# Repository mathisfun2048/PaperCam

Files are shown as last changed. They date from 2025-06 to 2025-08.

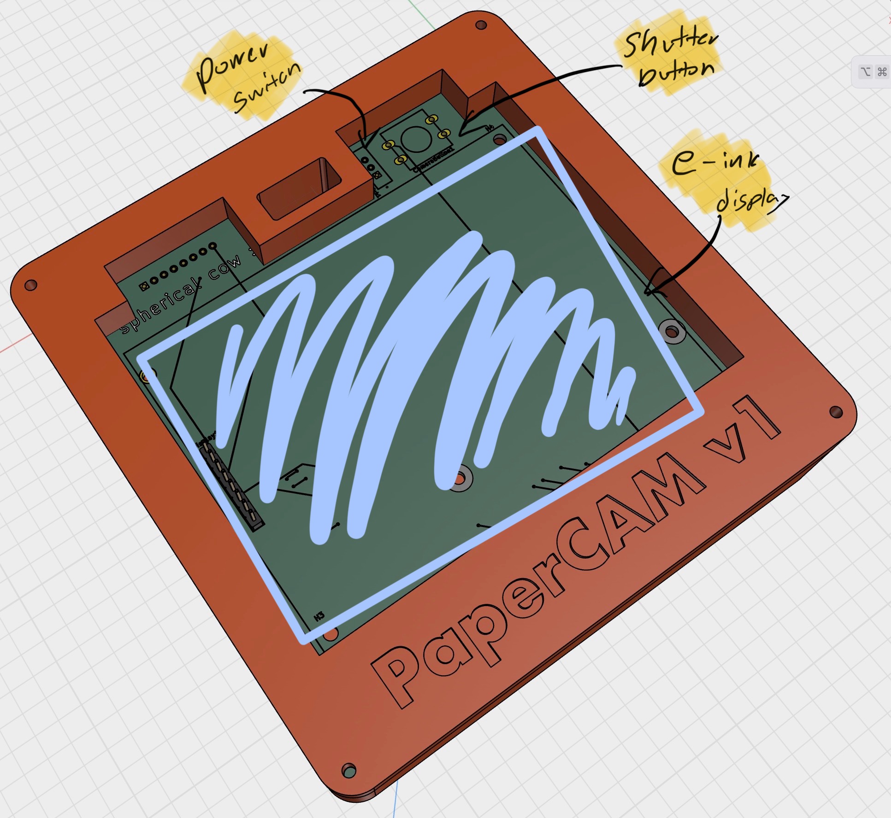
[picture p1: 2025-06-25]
assets/IMG_4889.jpeg

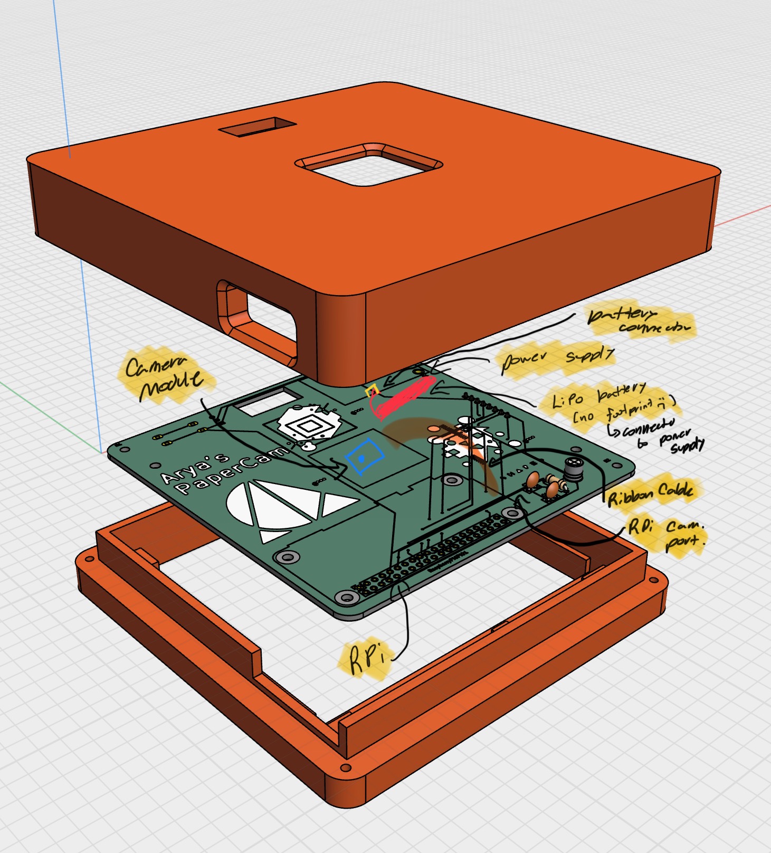
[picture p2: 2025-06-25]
assets/IMG_4890.jpg

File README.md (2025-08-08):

# PaperCam: My Thought Process Behind This Project



## Description and Exigence

This is my third attempt at hardware design, and it's been so much fun!

The concept arose when I came across ads for disposable cameras for summer camps on YouTube. I remembered the nostalgia of taking instant pictures and the intrinsic joy they bring, but within the context of instant cameras being 1) expensive and 2) harmful to the environment. I want to bridge this gap by creating a digital camera that feels like an instant camera. 

The first thing I think of with instant photography is not knowing exactly how the picture is going to turn out; rather, just taking it and hoping for the best. That's why instead of opting for an LCD display, I chose an E-Ink display. Not only does it use significantly less power, but it can also show an instant snapshot *after* taking the picture, mimicking the feeling of instant photography. 

Another goal I had for this project was to intentionally keep things minimalistic. In a world where technology can have so many features, I wanted to create something simple with one purpose: taking a picture. There's this one Japanese brand (Muji!) that I have been enthralled with for the past 7 years, mainly due to their product's simplicity. Keeping this in mind, I was very mindful of which parts I needed to use. The only user inputs, really, are a power switch and a capture button, nothing excessive but enough to take a picture. Moreover, the e-ink display shows a glimpse of the photo after it has been taken, not necessarily the most detailed, but accurate enough to capture the likeness of whatever is being captured. I hope that this camera will encourage me to try to create memories instead of the best "picture" I hope this camera will let me be less preoccupied with how things look but rather will force me to capture things authentically. 

Here is everything I sourced. A identical version can be found in the BOM tab at the bottom of the README. 

NOTE: I know some items can be found cheaper through other retailars: the only problem is that my parents will only let me buy from the retailors below. If the cost goes above the allocated cost for my project, I will hapilly pay out of my own pocket. I am grateful to have the opportunity to build this, and I cannot do so if I don't buy the parts from the retailors below. 

| item | quantity | cost | source | link |
| --- | --- | --- | --- | --- |
| Raspberry Pi Zero 2 W | 1 | 14.99  | microcenter | [https://www.microcenter.com/product/643085/raspberry-pi-zero-2-w](https://www.microcenter.com/product/643085/raspberry-pi-zero-2-w) |
| Camera | 1 | 29.25  | adafruit | [https://www.adafruit.com/product/5657](https://www.adafruit.com/product/5657) |
| e-ink display | 1 | 34.99  | amazon | [https://www.amazon.com/dp/B074NR1SW2](https://www.amazon.com/dp/B074NR1SW2) |
| 64gb SD Card | 1 | 0 | myself | n/a |
| LiPo Batter 2200mAh | 1 | 9.95 | adafruit | [https://www.adafruit.com/product/1781](https://www.adafruit.com/product/1781) |
| powerboost 1000c | 1 | 19.95  | adafruit | [https://www.adafruit.com/product/2465?srsltid=AfmBOop7pYqBCCEfueczVoFC1WawLn-4JDxrWe6MvBLNL__PzA9LbI22](https://www.adafruit.com/product/2465?srsltid=AfmBOop7pYqBCCEfueczVoFC1WawLn-4JDxrWe6MvBLNL__PzA9LbI22) |
| SPDT Switch | 1 | 0.95 | adafruit | [https://www.adafruit.com/product/805](https://www.adafruit.com/product/805) |
| 12mm Button | 1 | 5.95 | adafruit | [https://www.adafruit.com/product/1010](https://www.adafruit.com/product/1010) |
| Header for RPi | 1 | 1.75 | adafruit | [https://www.adafruit.com/product/3907](https://www.adafruit.com/product/3907) |
| 0.1uF Ceramic Capacitor | 2 | 1.95 | adafruit | [https://www.adafruit.com/product/753](https://www.adafruit.com/product/753) |
| 220uF Electrolytic Capacitor | 1 | 2.95 | adafruit | [https://www.adafruit.com/product/2192](https://www.adafruit.com/product/2192) |
| Screws M2.5 × 6 mm \* 5, M2.5 x 10 mm \* 4 | 9 | 16.95  | adafruit | [https://www.adafruit.com/product/3299](https://www.adafruit.com/product/3299) |
| Custom PCB | 1 | 8.6 | JCLPCB | [https://jlcpcb.com](https://jlcpcb.com/) |
| Total Cost | | ~148 |

## Schematic and PCB Design

I saw that with this project, spending all this time curating the BOM allowed my schematic and PCB design process to be significantly smoother. I was able to organically decide where components go such that the product can fulfill its purpose without having anything excess. I feel this starked my approach in my Hackpad design, where I flooded the PCB with an LED matrix, OLED, and encoder when perhaps the keys would have sufficed. The design of this project has been meditative, and I am grateful for that. One way I referenced this creative meditation in the design itself is through the inclusion of graphic design motifs I designed during the pandemic. The graphic design kept me sane then through its meditative nature, and I wanted to reference that simple creativity in the silkscreen. I will say that the silkscreen aesthetic starks the clean minimalistic nature of the CAD, and that is intentional: my graphic design motifs, in all their chaos, are a part of me and do not necessarily need to be advertised. To the user, I want the product to be simple elegant, and perfect for capturing memories. 

### Schematic

Screenshot 2025-07-02 at 4 30 53 AM

### PCB on Kicad

Screenshot 2025-07-02 at 4 30 31 AM

## Firmware

After I designed the PCB, I started on the firmware, the design of which garnered me the most personal growth. While I was able to exercise my research and design skills to a significantly larger extent in this project compared to Hackpad or Gamepad, the software designed for this is something I have never done before. I have never had multiple software files interact with each other in a product before. For instance, I started this project initially with just a runtime firmware, but then realized I needed to use shell too to initiate my code and the file structure and use the system to restart my Python code should it crash. I spent quite a bit coding, but I saw myself getting faster at it which amazed me. I started learning how to code maybe 2 years ago, and I am really proud of what I've been able to do here. 

Everything associated with the firmware can be found in the firmware directory. It has its own specialized README that explains what each file does. 

## CAD

After I was done with the code, I saved the hardest for last: CAD. I've never been good at CAD, but this project allowed me to show my style. When I did graphic design, I specialized in minimalistic designs which were meant to be abstract and aesthetically pleasing. I was highly influenced by the Bauhaus movement, and I am so glad I was able to incorporate that part of my personal style into this project. In keeping line with the "minimal" mindset, I wanted the design to be a simplified square Instax. That's why on the exterior form it almost looks like a kid's toy-- that is intentional. I don't want anything to distract from my camera being used to capture memories, even if it looks a tad blocky (I personally think it looks pretty cool). Making it look seamless on the outside was not easy, though. I utilized a top-case, bottom-case design where my PCB will screw into the bottom case before the top case is applied and the whole thing is screwed together. This required me to be able to hide my mounting screws inside the structure--the inside is much more chaotic than the clean exterior. For stability, I chose to indent the inside a tad so that the top case slides on and has a sense of rigidity. This is enhanced by the view-finder which acts as a "pole" holding everything together. I wanted my camera to not feel like something inherently precious, but rather something that can be taken places and used as a camera to capture memories. The only real adoration I have for it is the phrase "PaperCAM v1" on the user side of it. I want to remind myself that when I use this, it is something that I built and not something I simply bought. I want to remind myself that I have the agency to create things. 

Because everything is on a PCB this time, no fun illustrated wiring diagram :(. However, I did annotate the bellow images for y'all! 






## BOM

NOTE: I know some items can be found cheaper through other retailars: the only problem is that my parents will only let me buy from the retailors below. If the cost goes above teh allocated cost for my project, I will hapilly pay out of my own pocket. I am grateful to have the opportunity to build this, and I cannot do so if I don't buy the parts from the retailors below. 

| item | quantity | cost | source | link |
| --- | --- | --- | --- | --- |
| Raspberry Pi Zero 2 W | 1 | 14.99  | microcenter | [https://www.microcenter.com/product/643085/raspberry-pi-zero-2-w](https://www.microcenter.com/product/643085/raspberry-pi-zero-2-w) |
| Camera | 1 | 29.25  | adafruit | [https://www.adafruit.com/product/5657](https://www.adafruit.com/product/5657) |
| e-ink display | 1 | 34.99  | amazon | [https://www.amazon.com/dp/B074NR1SW2](https://www.amazon.com/dp/B074NR1SW2) |
| 64gb SD Card | 1 | 0 | myself | n/a |
| LiPo Batter 2200mAh | 1 | 9.95 | adafruit | [https://www.adafruit.com/product/1781](https://www.adafruit.com/product/1781) |
| powerboost 1000c | 1 | 19.95  | adafruit | [https://www.adafruit.com/product/2465?srsltid=AfmBOop7pYqBCCEfueczVoFC1WawLn-4JDxrWe6MvBLNL__PzA9LbI22](https://www.adafruit.com/product/2465?srsltid=AfmBOop7pYqBCCEfueczVoFC1WawLn-4JDxrWe6MvBLNL__PzA9LbI22) |
| SPDT Switch | 1 | 0.95 | adafruit | [https://www.adafruit.com/product/805](https://www.adafruit.com/product/805) |
| 12mm Button | 1 | 5.95 | adafruit | [https://www.adafruit.com/product/1010](https://www.adafruit.com/product/1010) |
| Header for RPi | 1 | 1.75 | adafruit | [https://www.adafruit.com/product/3907](https://www.adafruit.com/product/3907) |
| 0.1uF Ceramic Capacitor | 2 | 1.95 | adafruit | [https://www.adafruit.com/product/753](https://www.adafruit.com/product/753) |
| 220uF Electrolytic Capacitor | 1 | 2.95 | adafruit | [https://www.adafruit.com/product/2192](https://www.adafruit.com/product/2192) |
| Screws M2.5 × 6 mm \* 5, M2.5 x 10 mm \* 4 | 9 | 16.95  | adafruit | [https://www.adafruit.com/product/3299](https://www.adafruit.com/product/3299) |
| Custom PCB | 1 | 8.6 | JCLPCB | [https://jlcpcb.com](https://jlcpcb.com/) |
| Total Cost | | ~148 |

## Parting Words

If you've made it so far, thank you. This project has been really personal for me, I don't know why. In the process, I've discovered more of what I value in design and feel that I have been able to refine my personal style. Because of this project, I think I finally feel confident with CAD. In the coding portions, I learned that I can be an actual DEV and not someone who just does practice problems for some test.

Hackclub and Highway, thank you so much for the opportunity to design and hopefully implement this project. 

Until next time,
Arya

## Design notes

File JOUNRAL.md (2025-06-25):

title: PaperCam

author: Arya C.

description: this project is to create a digital camera that emulates the feeling of a instant camera through the use of an e-ink display.

created: 06/22/2025

total hours so far: 21 hours

# June 22

## 12PM -> 1PM (1 hour)
So I'm in the middle of my LightBox project (which you should totally check out too!) and I got this idea of making a digital camera feel more like a instant camera! Right now I'm not really researching parts or anything (focusing more on LightBox) but I wanted to start this and add my sketch so I remember my train of thought!



# June 23

## 3:30PM -> 5:30PM, 6PM -> 10PM (6 hours)

Spent some time researching various compoennts! A goal I have for this project is to absolulty minimize costs, something I had not looked at before. This was really, stupidly, hard because camera modules are so abundant... but I wanted to make one myself! I'm glad I was able to. Because of this, the PCB will be very minimalistic, but honestly, it might look better that way; it will fit the monocrome e-ink "instant" display. Here are the fruits from my labor in one cool table!

Shoutout to graphic for GPIO pins becasue this because it helped me so much!



| Section | Item | Part Number / Spec | Qty | Buy Link |
| --- | --- | --- | --- | --- |
| **Core** | | | | |
| | Raspberry Pi Zero 2 W | SC1176 | 1 | [microcenter](https://www.microcenter.com/product/643085/raspberry-pi-zero-2-w) |
| | Camera | — | 1 | [adafruit](https://www.adafruit.com/product/5657) |
| | 4.2″ E-Paper 400 × 300 SPI | Waveshare | 1 | [amazon](https://www.amazon.com/dp/B074NR1SW2) |
| | microSD Card 64 GB | SanDisk | 1 | [amazon](https://www.amazon.com/SanDisk-Extreme-microSDXC-Memory-Adapter/dp/B09X7C7LL1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) |
| **Power** | | | | |
| | 18650 Li-ion 2600 mAh | W2655B | 1 | [microcenter](https://www.microcenter.com/product/659302/performance-tools-18650-li-ion-recharge-battery) |
| | PowerBoost 1000 C | Adafruit 1944 | 1 | [adafruit](https://www.adafruit.com/product/2465?srsltid=AfmBOop7pYqBCCEfueczVoFC1WawLn-4JDxrWe6MvBLNL__PzA9LbI22) |
| | Main Power Switch SPDT (TH) | 805 | 1 | [adafruit](https://www.adafruit.com/product/805) |
| **User I/O** | | | | |
| |  12mm Square Tactile Button Switch | 1010 | 1 | [adafruit](https://www.adafruit.com/product/1010) |
| **Headers** | | | | |
| | Raspberry Pi Header | 3907 | 1 | [adafruit](https://www.adafruit.com/product/3907) |
| **Passives** | | | | |
| | 10 kΩ Resistor | 2784 | 1 | [adafruit](https://www.adafruit.com/product/2784) |
| | Decoupling 0.1 µF Ceramic Capacitor | 753 | 2 | [adafruit](https://www.adafruit.com/product/753) |
| | Bulk Cap 220uF 16V Electrolytic Capacitors  | 2192 | 1 | [adafruit](https://www.adafruit.com/product/2192) |
| **Mechanical / PCB** | | | | |
| |  Screws M2.5 × 6 mm * 5, M2.5 x 10 mm * 4 | 3299 | 8 | [adafruit](https://www.adafruit.com/product/3299) |
| | Custom PCB (2-layer 110 × 110 mm ENIG) | n/a | 1 | (JLCPCB / PCBWay whichever is cheaper) |

# June 24

## 10PM -> 3:30AM (5.5 hours)

Okay so I dont know what I was thinking! So when I first made my BOM, I relied on a lot of Digikey because they have everything... and then I saw their shipping! So to optimize, I re-did my BOM with primarily adafruit to keep shipping costs down (the parts I buy from microcenter will be in-person so no shipping). I don't know why but getting in the zen of making the schematic, I was able to think more clearly about the parts and how to use the PCB as an effective canvas for connecting. I don't know why but with my past interactions with PCBs I tried to make it as flashy and complicated as possible, but with my goal of minimalism with this project, I think I appreciate it as being an effective way to wire everything togehter. I am looking forward to see how it all turns out. In the meantime, here is a picture of my schematic!
Screenshot 2025-06-24 at 3 07 51 AM
Screenshot 2025-06-25 at 6 33 33 AM

## 3:30AM -> 4:30AM (1 hour)

Learning experience: plan footprints! So I found out that Kicad does not nativly support my footprints as the symbols are, so I needed to spend a hot minute going through the datasheets for each of my components to select the appropriate footprints. This is what I ended up with: 

Screenshot 2025-06-24 at 4 41 56 AM

Very excited to start building the PCB now!

## 3PM -> 4PM (1 hour)

Started desinging the PCB!

Screenshot 2025-06-24 at 3 19 32 PM

could not finish this in 1 session; I had work. 

# June 25

## 12AM -> 3AM (3 hours)

Finished with the PCB design! Very excited to see this in person :)

### PCB on Kicad
Screenshot 2025-06-25 at 3 04 05 AM
Screenshot 2025-06-25 at 6 34 42 AM
Screenshot 2025-06-25 at 12 37 25 PM

### Front Virtualization
Screenshot 2025-06-25 at 3 04 50 AM
Screenshot 2025-06-25 at 6 36 08 AM
Screenshot 2025-06-25 at 12 37 53 PM

### Back Virtualiation
Screenshot 2025-06-25 at 3 05 29 AM
Screenshot 2025-06-25 at 6 37 18 AM
Screenshot 2025-06-25 at 12 38 31 PM

Now onto software!

## 3AM -> 8AM (5 hours)

quick updated: I connected the LBO to pin 37 so I can get a low-battery notification!

okay so I finished the software!!!!!! 

This was significantly more complicated than coding my hackpad.... that took some intense coding.... yikes

I dont know what screenshots to attach here because, well, everything is just text. 

If you want to see a full software reveal, hit the software directory in this repo! There'll be a handy dandy repo there that will explain what each of the 3 files does!

Some things I learned: embeded design is really stupidly hard! If the internet did not exist, I have no clue how I could have found everything I needed. Thankfully, because the goal of my project is minimalism, the code wasn't too too complex but honestly, this was my first time dealing with software with multiple files working together. It was very fun learning how to do this, and I'm glad I gained this skill. 

Final stop: CAD case. 

## 8AM -> 1PM (4 hours)

I'm glad I'm getting better at cad! For this project, I had no inspo (gasp) I did the whole thign by myself, which I am really really proud of. My goal of minimalism probably helped--I want my final product to look like a glorified box which is easier to design haha. Anyways, I ventured with a new CAD software today: shapr3D. I normally use my IPad to sketch, so it was cool to be able to do 3D models on it--it felt a lot more natural than working CAD through fusion. I will post pictures when finished!

OKAY IM FINALLY DONE!!!


The design philosophy behind this is simplicity: I wanted the facade to be reminicent of a square instax camera, so I used a similar bulky square mootif as the central design. To add some variety, I included curved floureshes to both add visual contrast and make it easier to hold (no sharp corners!). 

Inside, the design is a tad bit more complicated. With numerous hidden screw holes, everything will be in place without harming the external facade. The "blocky" aesthetic I wanted to achieve is enhanced by the frame's rigidity afforded by the inlaid interlocking square and viewfinder. 

On the sides, there are access points to charge the device and swap out the sd card. 

## 1PM -> 2PM (1 hour)

I spent this time tidying this document up and adding all other documentation onto this repo! I hope you had fun reading this!

# I belive I have everything prepped for this project, including a Custom PCB, Custom Firmware, Custom Case, and associated components. The next step for me is to order my components and build this thing! Very excited

# One quick (and big) thank you to hack club for motivating me to do this project. Its ben an amazing run--thank you!

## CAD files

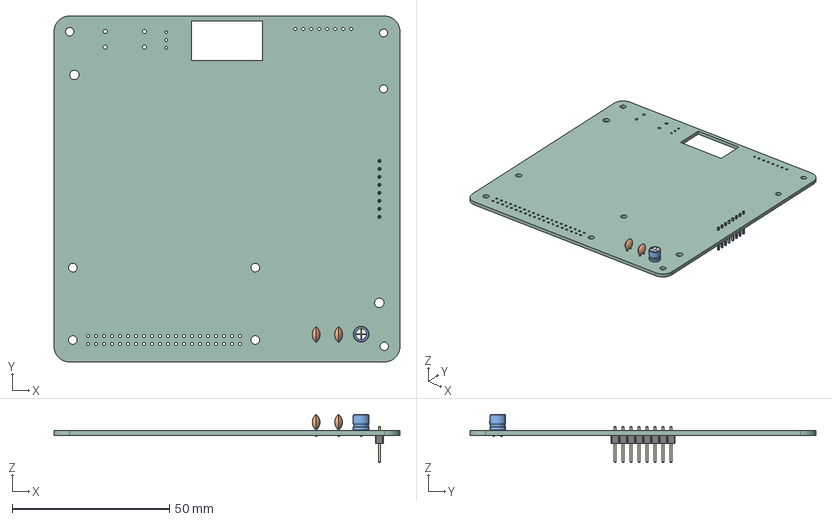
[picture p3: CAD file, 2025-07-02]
CAD/PaperCam_Kicad.step
110.0 x 110.0 x 15.3 mm
C_Disc_D5.0mm_W2.5mm_P2.50mm x 2
CP_Radial_D5.0mm_P2.50mm
PinHeader_1x08_P2.54mm_Vertical
PaperCam_Kicad_PCB

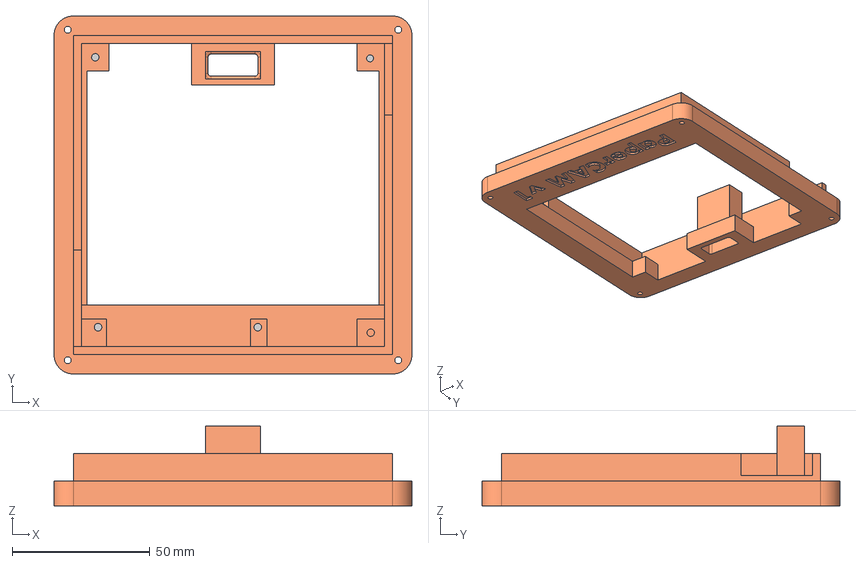
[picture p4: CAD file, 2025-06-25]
CAD/PaperCAM_STEP_Seperates/Bottom Piece.step
130.0 x 130.0 x 29.0 mm

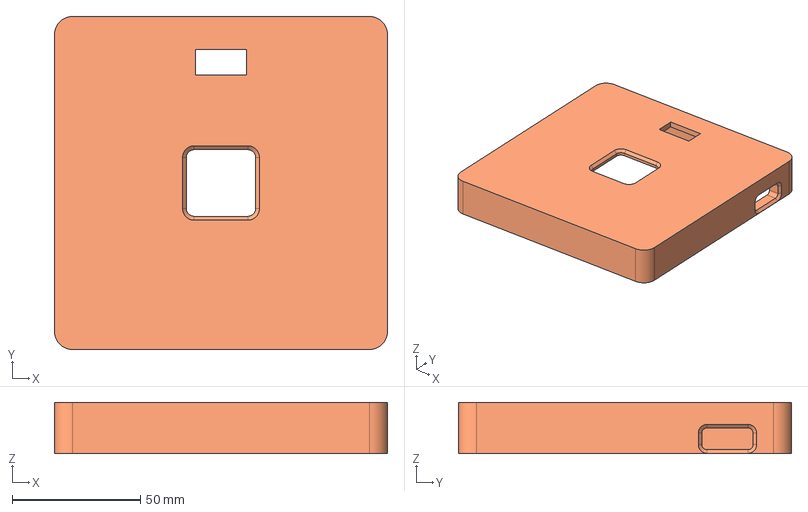
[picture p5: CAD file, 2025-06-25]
CAD/PaperCAM_STEP_Seperates/Top Piece.step
130.0 x 130.0 x 20.0 mm

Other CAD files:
Production/PaperCAM_STL_Seperates/Bottom Piece.stl
Production/PaperCAM_STL_Seperates/Top Piece.stl

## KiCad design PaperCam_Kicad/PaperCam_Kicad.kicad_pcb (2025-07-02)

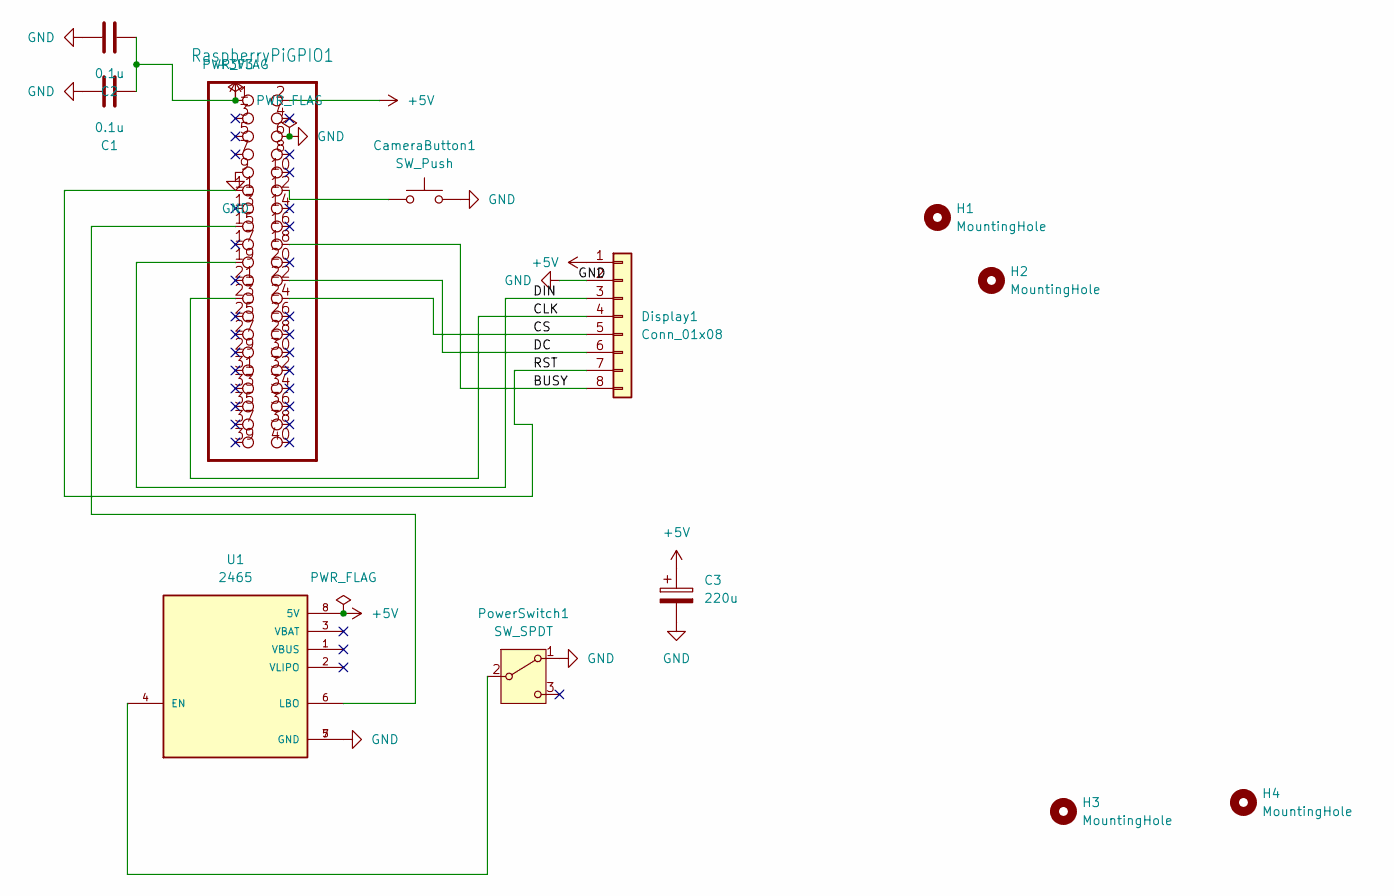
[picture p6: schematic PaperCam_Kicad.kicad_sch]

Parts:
C1, C2: 0.1u; C_Disc_D5.0mm_W2.5mm_P2.50mm
C3: 220u; CP_Radial_D5.0mm_P2.50mm
CameraButton1: SW_Push; SW_PUSH-12mm
Display1: Conn_01x08; PinHeader_1x08_P2.54mm_Vertical
H1, H2: MountingHole; MountingHole_2.7mm_M2.5
H3, H4: MountingHole; MountingHole_3mm
PowerSwitch1: SW_SPDT; SW_MINI-SPDT-SW
RaspberryPiGPIO1: Raspberry_Pi_Zero_Socketed_THT_FaceDown_MountingHoles
U1: 2465; MODULE_2465; PARTREV B

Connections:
+3V3: C1.1, C2.1, RaspberryPiGPIO1.1
+5V: C3.1, Display1.1, RaspberryPiGPIO1.2, U1.8 (5V)
/BUSY: Display1.8, RaspberryPiGPIO1.18
/CLK: Display1.4, RaspberryPiGPIO1.23
/CS: Display1.5, RaspberryPiGPIO1.24
/DC: Display1.6, RaspberryPiGPIO1.22
/DIN: Display1.3, RaspberryPiGPIO1.19
/RST: Display1.7, RaspberryPiGPIO1.11
GND: C1.2, C2.2, C3.2, CameraButton1.2, Display1.2, PowerSwitch1.1 (A), RaspberryPiGPIO1.6, RaspberryPiGPIO1.9, U1.5 (GND), U1.7 (GND)
unnamed: CameraButton1.1, RaspberryPiGPIO1.12
unnamed: PowerSwitch1.2 (B), U1.4 (EN)
unnamed: RaspberryPiGPIO1.15, U1.6 (LBO)

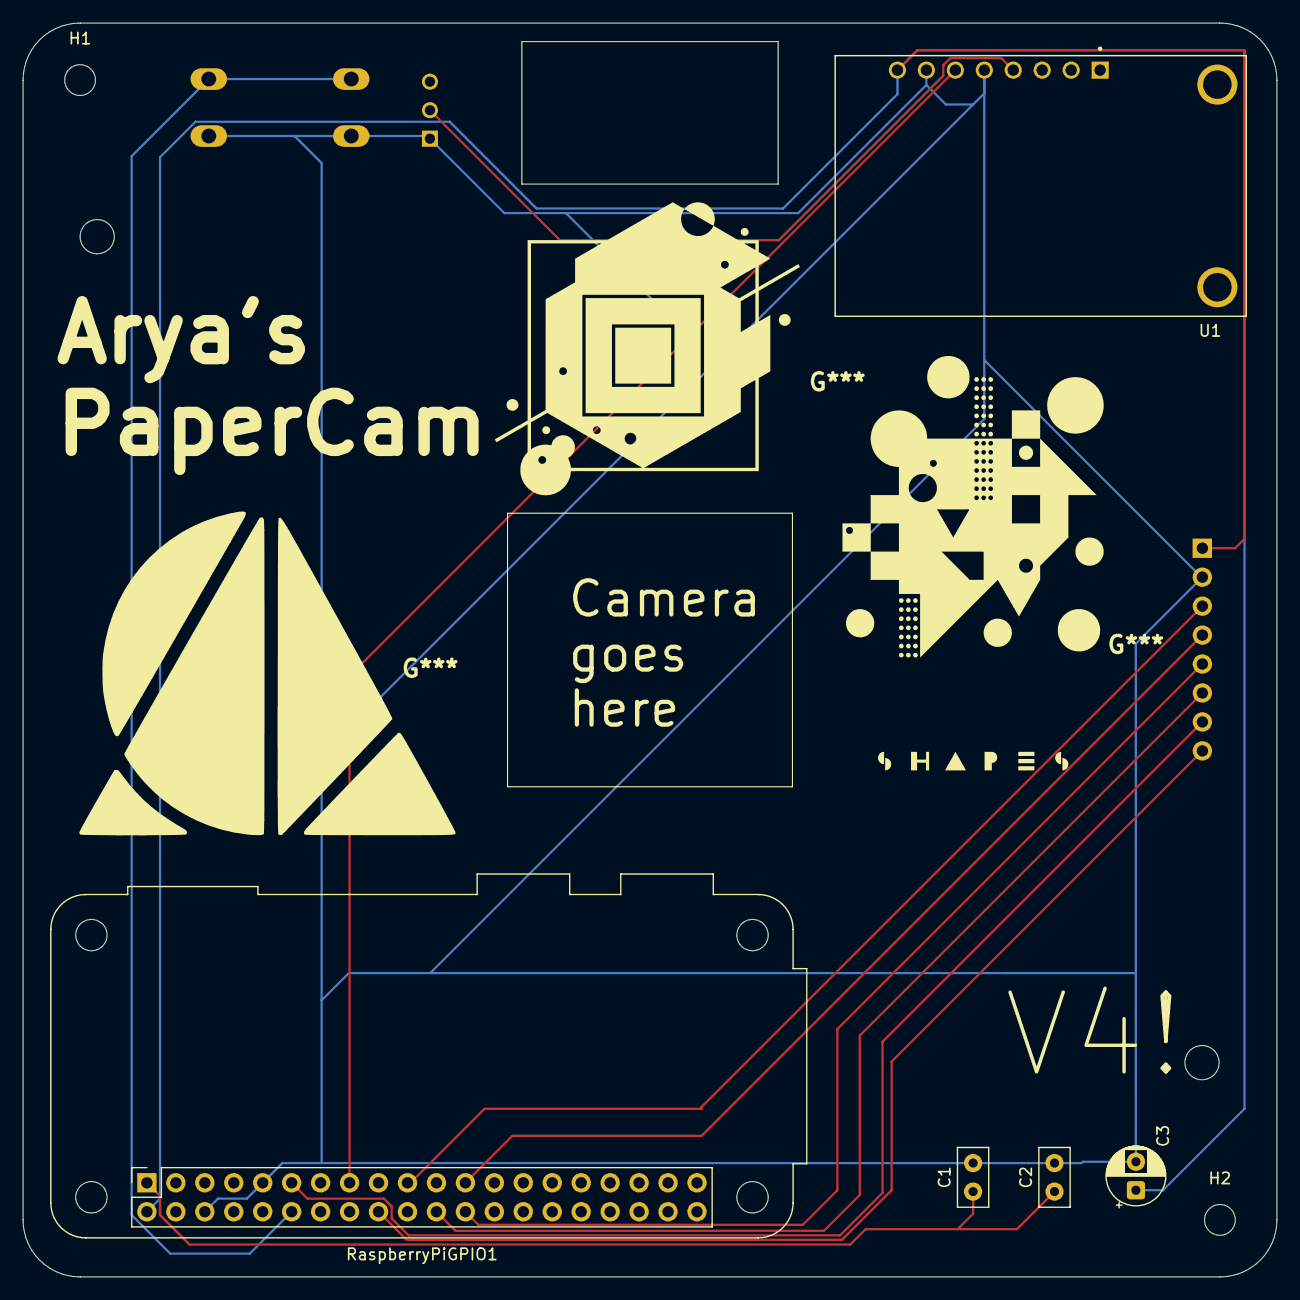
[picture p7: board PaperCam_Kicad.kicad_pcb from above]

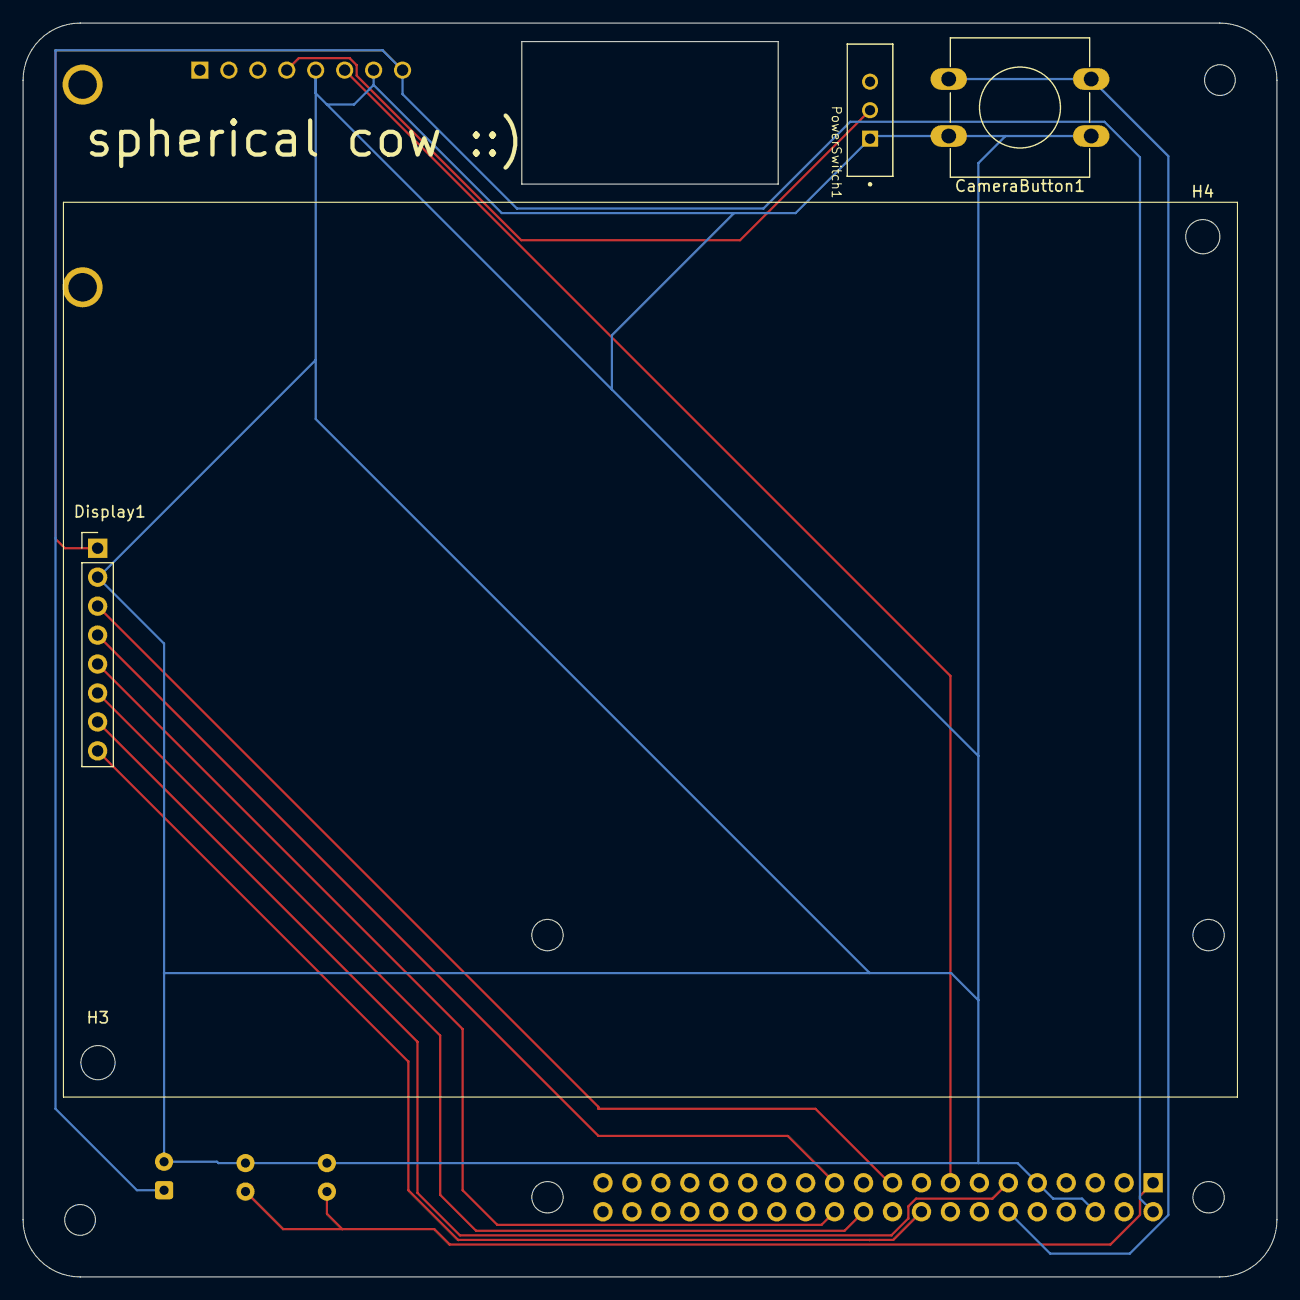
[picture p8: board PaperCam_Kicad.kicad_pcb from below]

Board: 2 copper layers, 110.0 x 110.0 mm, 12 parts (5 on the bottom side), 12 nets.

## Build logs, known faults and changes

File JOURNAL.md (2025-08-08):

---
title: "PaperCam"
author: "Arya CC"
description: "this project is to create a digital camera that emulates the feeling of a instant camera through the use of an e-ink display."
created_at: "06/22/2025"
---
total hours so far: 27 hours

# June 22

## 12PM -> 1PM (1 hour)
So I'm in the middle of my LightBox project (which you should totally check out too!) and I got this idea of making a digital camera feel more like a instant camera! Right now I'm not really researching parts or anything (focusing more on LightBox) but I wanted to start this and add my sketch so I remember my train of thought!



# June 23

## 3:30PM -> 5:30PM, 6PM -> 10PM (6 hours)

Spent some time researching various compoennts! A goal I have for this project is to absolulty minimize costs, something I had not looked at before. This was really, stupidly, hard because camera modules are so abundant... but I wanted to make one myself! I'm glad I was able to. Because of this, the PCB will be very minimalistic, but honestly, it might look better that way; it will fit the monocrome e-ink "instant" display. Here are the fruits from my labor in one cool table!

Shoutout to graphic for GPIO pins becasue this because it helped me so much!



| Section | Item | Part Number / Spec | Qty | Buy Link |
| --- | --- | --- | --- | --- |
| **Core** | | | | |
| | Raspberry Pi Zero 2 W | SC1176 | 1 | [microcenter](https://www.microcenter.com/product/643085/raspberry-pi-zero-2-w) |
| | Camera | — | 1 | [adafruit](https://www.adafruit.com/product/5657) |
| | 4.2″ E-Paper 400 × 300 SPI | Waveshare | 1 | [amazon](https://www.amazon.com/dp/B074NR1SW2) |
| | microSD Card 64 GB | SanDisk | 1 | [amazon](https://www.amazon.com/SanDisk-Extreme-microSDXC-Memory-Adapter/dp/B09X7C7LL1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) |
| **Power** | | | | |
| | 18650 Li-ion 2600 mAh | W2655B | 1 | [microcenter](https://www.microcenter.com/product/659302/performance-tools-18650-li-ion-recharge-battery) |
| | PowerBoost 1000 C | Adafruit 1944 | 1 | [adafruit](https://www.adafruit.com/product/2465?srsltid=AfmBOop7pYqBCCEfueczVoFC1WawLn-4JDxrWe6MvBLNL__PzA9LbI22) |
| | Main Power Switch SPDT (TH) | 805 | 1 | [adafruit](https://www.adafruit.com/product/805) |
| **User I/O** | | | | |
| |  12mm Square Tactile Button Switch | 1010 | 1 | [adafruit](https://www.adafruit.com/product/1010) |
| **Headers** | | | | |
| | Raspberry Pi Header | 3907 | 1 | [adafruit](https://www.adafruit.com/product/3907) |
| **Passives** | | | | |
| | 10 kΩ Resistor | 2784 | 1 | [adafruit](https://www.adafruit.com/product/2784) |
| | Decoupling 0.1 µF Ceramic Capacitor | 753 | 2 | [adafruit](https://www.adafruit.com/product/753) |
| | Bulk Cap 220uF 16V Electrolytic Capacitors  | 2192 | 1 | [adafruit](https://www.adafruit.com/product/2192) |
| **Mechanical / PCB** | | | | |
| |  Screws M2.5 × 6 mm * 5, M2.5 x 10 mm * 4 | 3299 | 8 | [adafruit](https://www.adafruit.com/product/3299) |
| | Custom PCB (2-layer 110 × 110 mm ENIG) | n/a | 1 | (JLCPCB / PCBWay whichever is cheaper) |

# June 24

## 10PM -> 3:30AM (5.5 hours)

Okay so I dont know what I was thinking! So when I first made my BOM, I relied on a lot of Digikey because they have everything... and then I saw their shipping! So to optimize, I re-did my BOM with primarily adafruit to keep shipping costs down (the parts I buy from microcenter will be in-person so no shipping). I don't know why but getting in the zen of making the schematic, I was able to think more clearly about the parts and how to use the PCB as an effective canvas for connecting. I don't know why but with my past interactions with PCBs I tried to make it as flashy and complicated as possible, but with my goal of minimalism with this project, I think I appreciate it as being an effective way to wire everything togehter. I am looking forward to see how it all turns out. In the meantime, here is a picture of my schematic!
Screenshot 2025-06-24 at 3 07 51 AM
Screenshot 2025-06-25 at 6 33 33 AM

## 3:30AM -> 4:30AM (1 hour)

Learning experience: plan footprints! So I found out that Kicad does not nativly support my footprints as the symbols are, so I needed to spend a hot minute going through the datasheets for each of my components to select the appropriate footprints. This is what I ended up with: 

Screenshot 2025-06-24 at 4 41 56 AM

Very excited to start building the PCB now!

## 3PM -> 4PM (1 hour)

Started desinging the PCB!

Screenshot 2025-06-24 at 3 19 32 PM

could not finish this in 1 session; I had work. 

# June 25

## 12AM -> 3AM (3 hours)

Finished with the PCB design! Very excited to see this in person :)

### PCB on Kicad
Screenshot 2025-06-25 at 3 04 05 AM
Screenshot 2025-06-25 at 6 34 42 AM
Screenshot 2025-06-25 at 12 37 25 PM

### Front Virtualization
Screenshot 2025-06-25 at 3 04 50 AM
Screenshot 2025-06-25 at 6 36 08 AM
Screenshot 2025-06-25 at 12 37 53 PM

### Back Virtualiation
Screenshot 2025-06-25 at 3 05 29 AM
Screenshot 2025-06-25 at 6 37 18 AM
Screenshot 2025-06-25 at 12 38 31 PM

Now onto software!

## 3AM -> 8AM (5 hours)

quick updated: I connected the LBO to pin 37 so I can get a low-battery notification!

okay so I finished the software!!!!!! 

This was significantly more complicated than coding my hackpad.... that took some intense coding.... yikes

I dont know what screenshots to attach here because, well, everything is just text. 

If you want to see a full software reveal, hit the software directory in this repo! There'll be a handy dandy repo there that will explain what each of the 3 files does!

Some things I learned: embeded design is really stupidly hard! If the internet did not exist, I have no clue how I could have found everything I needed. Thankfully, because the goal of my project is minimalism, the code wasn't too too complex but honestly, this was my first time dealing with software with multiple files working together. It was very fun learning how to do this, and I'm glad I gained this skill. 

Final stop: CAD case. 

## 8AM -> 1PM (4 hours)

I'm glad I'm getting better at cad! For this project, I had no inspo (gasp) I did the whole thign by myself, which I am really really proud of. My goal of minimalism probably helped--I want my final product to look like a glorified box which is easier to design haha. Anyways, I ventured with a new CAD software today: shapr3D. I normally use my IPad to sketch, so it was cool to be able to do 3D models on it--it felt a lot more natural than working CAD through fusion. I will post pictures when finished!

OKAY IM FINALLY DONE!!!


The design philosophy behind this is simplicity: I wanted the facade to be reminicent of a square instax camera, so I used a similar bulky square mootif as the central design. To add some variety, I included curved floureshes to both add visual contrast and make it easier to hold (no sharp corners!). 

Inside, the design is a tad bit more complicated. With numerous hidden screw holes, everything will be in place without harming the external facade. The "blocky" aesthetic I wanted to achieve is enhanced by the frame's rigidity afforded by the inlaid interlocking square and viewfinder. 

On the sides, there are access points to charge the device and swap out the sd card. 

## 1PM -> 2PM (1 hour)

I spent this time tidying this document up and adding all other documentation onto this repo! I hope you had fun reading this!

# July 2 

## 12AM -> 2AM (2 hours)

So I was going to print but then wanted to double check... uh oh! I had massive errors on my PCB (some extra wiring that ddin't make sense). So to fix that, I got rid of my resistor to chose an internal pull up instead. This will save me some soldering haha. In this change, I made some edits to the wiring too, making it look pretier and use no vias. I also enlarged the viewfinder a bit on all sides to allow for a easier passthrough 3d print. 

Something I learned was that having redundant pahts is good! Because of that, for my 5V lines, I did implmeneted a star topology instead of my previous bus topology. Because doing STAR for GND would be a bit overkill, I did a bus initilaly, and then added a ton of redundant paths. 

Screenshot 2025-07-02 at 2 40 59 AM

Screenshot 2025-07-02 at 2 09 57 AM

## 4AM -> 4:30AM (0.5 hours)

I found out that my display was misrouted ... fixed it. 

Screenshot 2025-07-02 at 4 30 31 AM

Screenshot 2025-07-02 at 4 30 53 AM

for future reference:
Screenshot 2025-07-02 at 4 35 25 AM

# I belive I have everything prepped for this project, including a Custom PCB, Custom Firmware, Custom Case, and associated components. The next step for me is to order my components and build this thing! Very excited

# One quick (and big) thank you to hack club for motivating me to do this project. Its ben an amazing run--thank you!

# August 2nd 6AM -> 11 PM (17 hours) (running)

so I physically built it but the camera that shipped is defective... adafruit is sending me a replacement but it has unfortunatly not arrived; the ETA is august 20th :(

Here is some pictures of my build process though!

I tested the code on my bigger raspberry pi 3b+ and then later ported teh sd card onto a pi zero 2w and everythign works!









Here is the youtube video for a better walk through: https://youtu.be/G1qLKi6BtbE?feature=shared

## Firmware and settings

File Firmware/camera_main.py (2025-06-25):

#!/usr/bin/env python3

import time
import datetime
import shutil
from pathlib import Path
from PIL import Image, ImageOps, ImageDraw, ImageFont
import RPi.GPIO as GPIO
from picamera2 import Picamera2
import logging

PHOTO_DIR = Path("/home/pi/photos")
PHOTO_DIR.mkdir(parents=True, exist_ok=True)

BUTTON_PIN = 17
BAT_LOW_PIN = 26

RST_PIN = 24
DC_PIN = 25
CS_PIN = 8
BUSY_PIN = 23
SPI_CLK = 11
SPI_DIN = 10

DISPLAY_WIDTH = 400
DISPLAY_HEIGHT = 300
DISK_SPACE_THRESHOLD = 100 * 1024 * 1024

logging.basicConfig(
    level=logging.INFO,
    format="%(asctime)s %(levelname)s: %(message)s",
    handlers=[logging.FileHandler("/home/pi/camera.log"), logging.StreamHandler()]
)
logger = logging.getLogger("papercam")

try:
    from waveshare_epd import epd4in2
    epd = epd4in2.EPD()
    epd.init()
    epd.Clear()
    logger.info("E‑ink display initialized")
except Exception as e:
    logger.error(f"E‑ink init failed: {e}")
    epd = None

camera = Picamera2()
camera.configure(camera.create_still_configuration(main={"size": (4056, 3040)}, display=None))
camera.start()
time.sleep(2)
logger.info("Camera initialized")

GPIO.setwarnings(False)
GPIO.setmode(GPIO.BCM)
GPIO.setup(BUTTON_PIN, GPIO.IN, pull_up_down=GPIO.PUD_UP)
GPIO.setup(BAT_LOW_PIN, GPIO.IN, pull_up_down=GPIO.PUD_UP)
logger.info("GPIO setup complete")

def is_battery_low():
    return GPIO.input(BAT_LOW_PIN) == GPIO.LOW

def check_sd_space():
    _, _, free = shutil.disk_usage(str(PHOTO_DIR))
    return free > DISK_SPACE_THRESHOLD

def capture_photo():
    ts = datetime.datetime.now().strftime("%Y%m%d_%H%M%S")
    path = PHOTO_DIR / f"photo_{ts}.jpg"
    logger.info(f"Capturing {path.name}...")
    camera.capture_file(str(path))
    return path

def show_bitmap(img):
    if epd:
        epd.display(epd.getbuffer(img))

def display_message(text):
    if not epd:
        return
    
    img = Image.new('1', (DISPLAY_WIDTH, DISPLAY_HEIGHT), 255)
    draw = ImageDraw.Draw(img)
    font = ImageFont.load_default()
    
    bbox = draw.textbbox((0, 0), text, font=font)
    w, h = bbox[2] - bbox[0], bbox[3] - bbox[1]
    
    draw.text(((DISPLAY_WIDTH - w)//2, (DISPLAY_HEIGHT - h)//2), text, font=font, fill=0)
    show_bitmap(img)

def flash_once(img, delay=0.5):
    show_bitmap(img)
    time.sleep(delay)
    inv = ImageOps.invert(img.convert("L")).convert("1")
    show_bitmap(inv)
    time.sleep(delay)
    show_bitmap(img)

def display_sd_full():
    logger.warning("SD nearly full – displaying warning")
    display_message("SD CARD FULL")

def display_low_battery():
    logger.warning("Battery low – displaying warning")
    display_message("LOW BATTERY")

def display_ready():
    display_message("Ready")


if epd:
    display_ready()


def display_processing():
    if epd:
        display_message("PROCESSING...")

def process_and_display(photo_path):
    if not epd:
        return
    
    img = None
    bw = None
    try:
        display_processing()
        
        img = Image.open(photo_path).convert('L')
        img = ImageOps.fit(img, (DISPLAY_WIDTH, DISPLAY_HEIGHT), Image.Resampling.LANCZOS)
        bw = img.convert('1')
        show_bitmap(bw)
        logger.info("Displayed captured image")
    except Exception as e:
        logger.error(f"Display error: {e}")
    finally:
        for obj in (bw, img):
            try:
                obj and obj.close()
            except Exception:
                pass

def cleanup():
    GPIO.cleanup()
    try:
        camera.close()
    except Exception:
        pass
    if epd:
        try:
            epd.sleep()
        except Exception:
            pass
    logger.info("Shutdown complete")

def main():
    logger.info("PaperCam ready – waiting for button press")
    battery_warned = False
    last_battery_check = 0
    
    try:
        while True:
            current_time = time.time()
            
            if current_time - last_battery_check > 5:
                if is_battery_low():
                    if not battery_warned:
                        display_low_battery()
                        battery_warned = True
                        logger.warning("Battery low - photos may not save properly")
                else:
                    if battery_warned:
                        logger.info("Battery level recovered")
                    battery_warned = False
                last_battery_check = current_time

            if GPIO.input(BUTTON_PIN) == GPIO.LOW:
                time.sleep(0.1)
                if GPIO.input(BUTTON_PIN) == GPIO.LOW:
                    if battery_warned:
                        logger.warning("Taking photo with low battery")
                    
                    if not check_sd_space():
                        display_sd_full()
                    else:
                        photo = capture_photo()
                        process_and_display(photo)
                    
                    while GPIO.input(BUTTON_PIN) == GPIO.LOW:
                        time.sleep(0.1)
            
            time.sleep(0.05)
            
    except KeyboardInterrupt:
        logger.info("Keyboard interrupt – shutting down")
    except Exception as e:
        logger.exception(f"Unhandled exception: {e}")
    finally:
        cleanup()

if __name__ == "__main__":
    main()

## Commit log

2025-06-25 added pcb files
    [PaperCam_Kicad.kicad_pcb, PaperCam_Kicad.kicad_sch]
2025-06-25 added software
    [PaperCam_Kicad.kicad_sch]
2025-06-25 cad files
    [PaperCam_Kicad.kicad_pcb, PaperCam_Kicad.step]
2025-06-25 added BOM and Gerbers
    [PaperCam_Kicad.kicad_pcb, PaperCam_Kicad.kicad_sch, PaperCam_Kicad.step]
2025-06-25 added some stuff
    [BOM for PaperCAM - Sheet1.csv, Bottom Piece.step, Bottom Piece.stl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]
2025-07-02 Update BOM for PaperCAM - Sheet1.csv
    [BOM for PaperCAM - Sheet1.csv]
2025-07-02 updated pcb design
    [BOM for PaperCAM - Sheet1.csv, Bottom Piece.step, Bottom Piece.stl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]
2025-07-02 fixed wiring
    [PaperCam_Kicad-B_Cu.gbr, PaperCam_Kicad-B_Mask.gbr, PaperCam_Kicad-B_Paste.gbr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]
2025-07-02 fixed keyboard
    [PaperCam_Kicad-B_Cu.gbr, PaperCam_Kicad-B_Mask.gbr, PaperCam_Kicad-B_Paste.gbr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]
